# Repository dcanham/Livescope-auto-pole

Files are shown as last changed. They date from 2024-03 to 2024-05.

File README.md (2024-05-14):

# Livescope-auto-pole

# Livescope Pole V1

This project is for controlling a 1 1/8" inch pole that your livescope is mounted on, however it can be updated to fit other poles. Lots of code here for testing, so each folder will be explained below. Bluetooth_and_AP_Mode is the main code that is working and partially tested, it powers on, looks for the most recently connected device, if it does not find it, it will go into "AP" mode where your phone can connect to its wifi. Then go to a browser and go to 192.168.4.1 and a webpage should show. Click "scan" and it will look for bluetooth devices in the area. Select the device you wish to connect and it will shut off the AP and start working. Now each time the device boots up it will look for that device. 

## Parts list:
- ESP32 with 18650: https://a.co/d/enj4STK
- 3v to 5v step up: https://www.pololu.com/product/2562 (required as the ESP only outputs 5v if on USB power)
- Servo: https://a.co/d/6YfNTrJ
- 1" ram mount: https://a.co/d/4ML1X51
- Wireless BT Remote: https://a.co/d/i9t7pQf
- Box: Printed in PETG, files can be found 3d Printed Parts folder. 
- Misc wires and solder
- A 1 and 1/8 livescope pole with hole at top, I used the summit fishing pole. 

## To do:
- Clean Up Code
- Test other bluetooth remotes
- Add comments
- Ajust gears to have deeper teeth for better grip

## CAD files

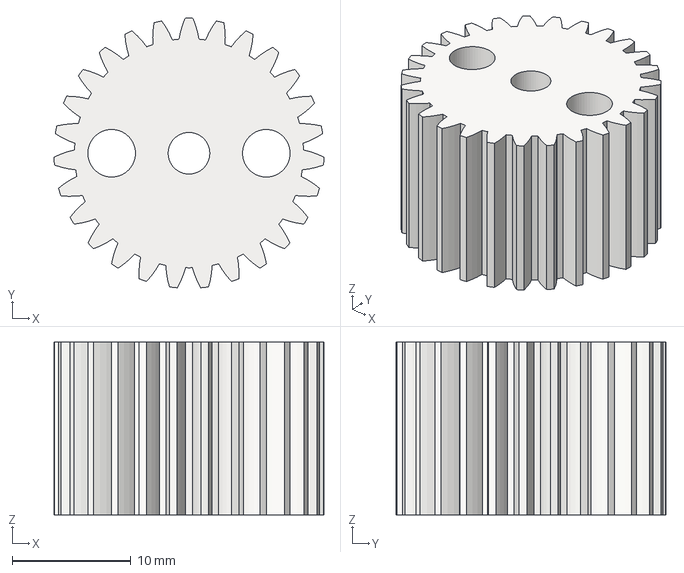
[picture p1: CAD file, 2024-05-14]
3d Printed parts/Little_gear.step
22.7 x 22.7 x 14.5 mm

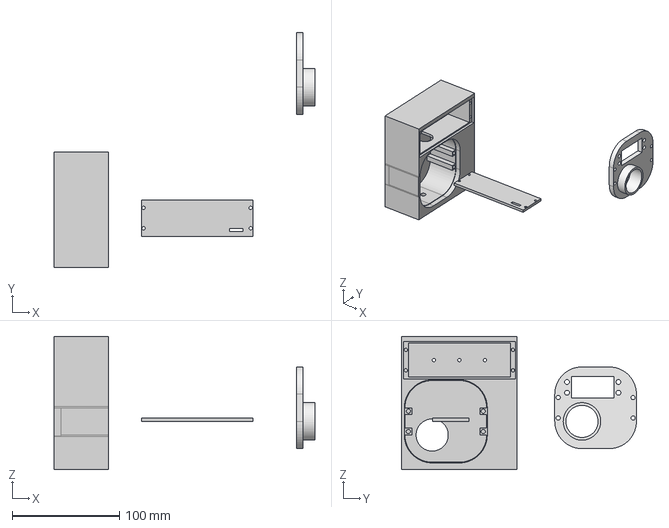
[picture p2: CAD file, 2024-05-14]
3d Printed parts/Livescope_pole_box.step
243.4 x 219.1 x 124.4 mm

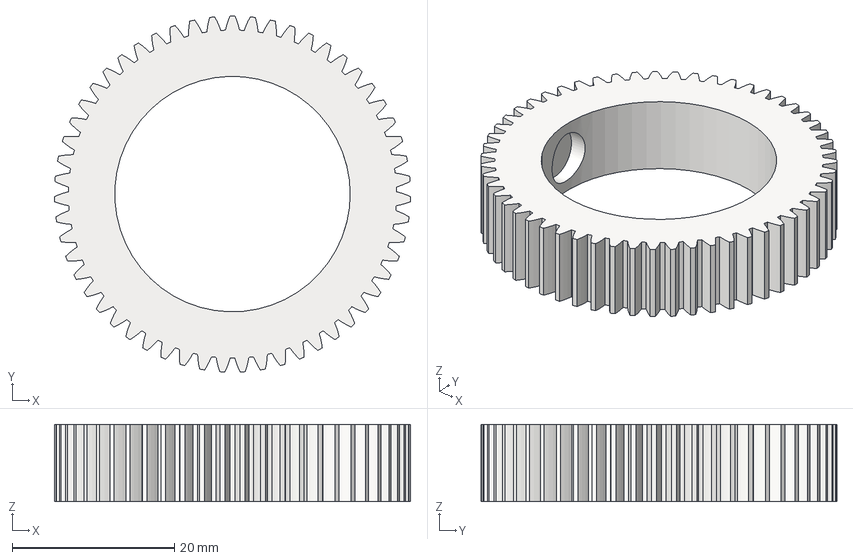
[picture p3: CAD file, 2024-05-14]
3d Printed parts/Big_gear.step
43.9 x 43.8 x 9.53 mm

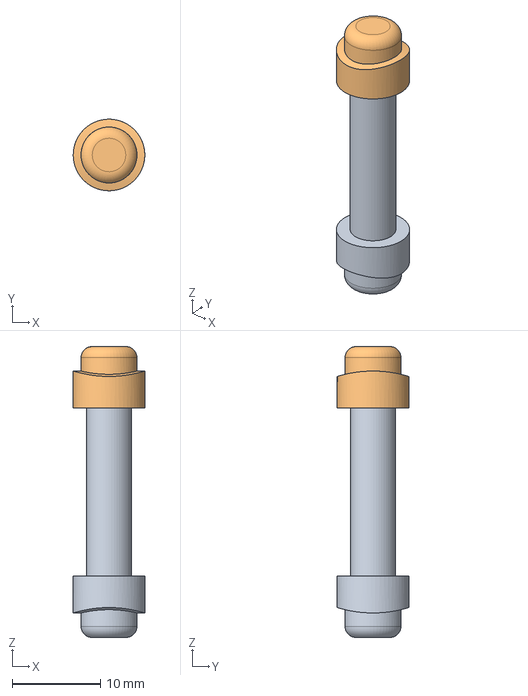
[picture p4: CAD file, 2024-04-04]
3d Printed parts/TPU_Inner_Spring_Rod.step
8.12 x 8.13 x 33.0 mm

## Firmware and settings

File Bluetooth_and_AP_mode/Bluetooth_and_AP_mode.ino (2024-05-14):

#include <WiFi.h>
#include <WebServer.h>
#include <BLEDevice.h>
#include <BLEUtils.h>
#include <BLEScan.h>
#include <BLEAdvertisedDevice.h>
#include <ESP32Servo.h>
#include <EEPROM.h>
#include <Arduino.h>

// Set up variables and things
const char* ssid = "ESP32-AP";
const char* password = "password";
bool isConnected = false;
bool alreadyPrinted = false;
bool wifiOff = false;
bool firstBoot = true;
bool addressEmpty = false;
const int servoPin = 22; // GPIO pin connected to the servo
const int pulseMin = 1250; // Minimum pulse width in microseconds
const int pulseMax = 1750; // Maximum pulse width in microseconds
const int pulseMid = 1500; // Middle pulse width to represent the mid-point
BLEClient* pClient;
WebServer server(80);
BLEScan* pBLEScan;
std::vector<BLEAdvertisedDevice> discoveredDevices;
BLEUUID HID_SERVICE_UUID;
BLEUUID HID_REPORT_CHAR_UUID;
#define CLIENT_CHARACTERISTIC_CONFIG_UUID "00002902-0000-1000-8000-00805f9b34fb"
#define SERVO_PIN 16
#define LEFT_LIMIT 0
#define RIGHT_LIMIT 180
#define EEPROM_ADDR_START 0
#define MAX_STRING_LENGTH 20  // Maximum length of the string to be stored in EEPROM
#define EEPROM_SIZE 200


Servo myservo;
Servo servo;
uint8_t lastButtonState = 0;
int servoPosition = 90;
bool processHIDReport = true;





class MyAdvertisedDeviceCallbacks : public BLEAdvertisedDeviceCallbacks {
public:
  void onResult(BLEAdvertisedDevice advertisedDevice) {
    discoveredDevices.push_back(advertisedDevice);
  }
};

String getLastConnectedDeviceAddress() {
  String data = "";
  char byteRead;
  for (int i = 0; i < MAX_STRING_LENGTH; i++) {
    byteRead = char(EEPROM.read(EEPROM_ADDR_START + i));
    //Serial.print("Read byte: ");
    //Serial.println(byteRead);
    if (byteRead == '\0') {
      break;  // Stop reading if null terminator is encountered
    }
    data += byteRead;
  }

  // Print the read data to serial
  Serial.println("Data read from EEPROM:");
  Serial.println(data);
  return data;
}


void writeToEEPROM(String data) {
  int length = data.length();
  if (length > MAX_STRING_LENGTH - 1) {  // Ensure data fits within EEPROM size
    Serial.println("Data exceeds EEPROM capacity. Truncating...");
    length = MAX_STRING_LENGTH - 1;
    data.substring(0, length);  // Truncate data
  }

  Serial.println("Printing below to EEPROM: ");
  Serial.println(data);
  for (int i = 0; i < length; i++) {
    char byteToWrite = data[i];
    EEPROM.write(EEPROM_ADDR_START + i, byteToWrite);
    //Serial.print("Wrote byte: ");
    //Serial.println(byteToWrite);
  }
  EEPROM.write(EEPROM_ADDR_START + length, '\0');  // Null-terminate the string
  EEPROM.commit();                                 // Commit the changes to EEPROM
}


void handleRoot() {
  String page = "<html><body>";
  page += "<h1>Welcome to ESP32 Web Server</h1>";
  page += "<button onclick=\"window.location.href='/scan'\">Scan</button>";
  page += "</body></html>";
  server.send(200, "text/html", page);
}

void handleScan() {
  discoveredDevices.clear();
  BLEScanResults foundDevices = pBLEScan->start(5);
  server.sendHeader("Location", "/results", true);
  server.send(302, "text/plain", "");
}

void handleResults() {
  String page = "<html><body>";
  page += "<h1>Scan Results</h1>";
  page += "<ul>";
  for (size_t i = 0; i < discoveredDevices.size(); ++i) {
    BLEAdvertisedDevice device = discoveredDevices[i];
    BLEAddress address = device.getAddress();
    String name = device.getName().c_str();
    page += "<li>Address: " + String(address.toString().c_str()) + ", Name: " + String(name.c_str()) + " <button onclick=\"window.location.href='/connect?address=" + String(address.toString().c_str()) + "'\">Connect</button></li>";
  }
  page += "</ul>";

  // Add rescan button
  page += "<button onclick=\"window.location.href='/scan'\">Rescan</button>";

  page += "</body></html>";
  server.send(200, "text/html", page);
}

void registerForNotifications() {
  Serial.println("Started registerForNotifications part");
  BLERemoteService* pService = pClient->getService(HID_SERVICE_UUID);
  if (pService) {
    Serial.println("HID Service found.");
    Serial.print("HID Service UUID: ");
    Serial.println(pService->getUUID().toString().c_str());

    BLERemoteCharacteristic* pCharacteristic = pService->getCharacteristic(HID_REPORT_CHAR_UUID);
    if (pCharacteristic) {
      Serial.println("HID Report Characteristic found.");
      Serial.print("HID Report Characteristic UUID: ");
      Serial.println(pCharacteristic->getUUID().toString().c_str());

      // Use the hardcoded CLIENT_CHARACTERISTIC_CONFIG_UUID here
      const char* CCCD_UUID = "00002902-0000-1000-8000-00805f9b34fb";
      BLEUUID cccdUUID(CCCD_UUID);
      BLERemoteDescriptor* pDescriptor = pCharacteristic->getDescriptor(cccdUUID);
      if (pDescriptor) {
        Serial.println("Client Characteristic Configuration Descriptor found.");
        Serial.print("Client Characteristic Configuration Descriptor UUID: ");
        Serial.println(pDescriptor->getUUID().toString().c_str());

        Serial.println("Registering for notifications on HID report characteristic.");
        pDescriptor->writeValue((uint8_t*)"\x01\x00", 2);  // Enable notifications (0x0001)
        pCharacteristic->registerForNotify(notifyCallback);
        Serial.println("Registered for notifications.");
      } else {
        Serial.println("Failed to find Client Characteristic Configuration Descriptor.");
      }
    } else {
      Serial.println("Failed to find HID Report Characteristic.");
    }
  } else {
    Serial.println("Failed to find HID Service.");
  }
}

void handleConnect() {
  Serial.println("Handling connect request...");
  String addressParam = server.arg("address");  // Get the BLE device address from the URL parameter
  addressParam.trim();                          // Remove leading and trailing whitespace characters

  Serial.println("Connecting to device at address: " + addressParam);

  if (addressParam.length() == 0) {
    Serial.println("No address provided.");
    server.send(400, "text/plain", "No address provided.");
    return;
  }

  BLEAddress address = BLEAddress(addressParam.c_str());  // Convert the address string to BLEAddress object

  // Check if already connected
  if (isConnected) {
    Serial.println("Already connected to a device.");
    server.send(200, "text/plain", "Already connected to a device.");
    return;
  }

  Serial.println("Attempting to connect to the device...");

  // Initialize BLE client
  pClient = BLEDevice::createClient();  // Removed local declaration to use the global one
  if (!pClient) {
    Serial.println("Failed to create BLE client.");
    server.send(500, "text/plain", "Failed to create BLE client.");
    return;
  }

  // Attempt to connect to the device
  if (pClient->connect(address)) {
    Serial.println("Connected to the device.");
    isConnected = true;  // Set connection flag to true
    // Save the connected device address to EEPROM
    writeToEEPROM(addressParam);
    Serial.println("Written to EEProm");


    Serial.println("Connect request handled. Lets anaylze ");

    // Get the HID service UUID and HID report characteristic UUID
    std::map<std::string, BLERemoteService*>* services = pClient->getServices();
    if (services) {
      for (auto& service : *services) {
        std::map<std::string, BLERemoteCharacteristic*>* characteristics = service.second->getCharacteristics();
        if (characteristics) {
          for (auto& characteristic : *characteristics) {
            if (characteristic.second->canNotify()) {
              if (characteristic.second->getUUID().equals(BLEUUID((uint16_t)0x2A4D))) {  // HID report characteristic UUID is 0x2A4D
                Serial.println("Found HID report characteristic.");
                HID_SERVICE_UUID = BLEUUID(service.first);
                HID_REPORT_CHAR_UUID = BLEUUID(characteristic.first);
                registerForNotifications();
                return;
              }
            }
          }
        }
      }
    }
  } else {
    Serial.println("Failed to connect to the device.");
    server.send(500, "text/plain", "Failed to connect to the device.");
  }

  Serial.println("Failed to find HID service or report characteristic.");
}

void handleConnectEEProm(String addressParam) {
  Serial.println("Handling connect request...");
  //String addressParam = server.arg("address"); // Get the BLE device address from the URL parameter
  addressParam.trim();  // Remove leading and trailing whitespace characters

  Serial.println("Connecting to device at address: " + addressParam);

  if (addressParam.length() == 0) {
    Serial.println("No address provided.");
    server.send(400, "text/plain", "No address provided.");
    return;
  }

  BLEAddress address = BLEAddress(addressParam.c_str());  // Convert the address string to BLEAddress object

  // Check if already connected
  // if (isConnected) {
  //     Serial.println("Already connected to a device.");
  //     server.send(200, "text/plain", "Already connected to a device.");
  //     return;
  // }

  Serial.println("Attempting to connect to the device...");

  // Initialize BLE client
  pClient = BLEDevice::createClient();  // Removed local declaration to use the global one
  if (!pClient) {
    Serial.println("Failed to create BLE client.");
    //server.send(500, "text/plain", "Failed to create BLE client.");
    return;
  }

  // Attempt to connect to the device
  if (pClient->connect(address)) {
    Serial.println("Connected to the device.");
    isConnected = true;  // Set connection flag to true
    // Save the connected device address to EEPROM
    writeToEEPROM(addressParam);
    Serial.println("Written to EEProm");


    Serial.println("Connect request handled. Lets anaylze ");

    // Get the HID service UUID and HID report characteristic UUID
    std::map<std::string, BLERemoteService*>* services = pClient->getServices();
    if (services) {
      for (auto& service : *services) {
        std::map<std::string, BLERemoteCharacteristic*>* characteristics = service.second->getCharacteristics();
        if (characteristics) {
          for (auto& characteristic : *characteristics) {
            if (characteristic.second->canNotify()) {
              if (characteristic.second->getUUID().equals(BLEUUID((uint16_t)0x2A4D))) {  // HID report characteristic UUID is 0x2A4D
                Serial.println("Found HID report characteristic.");
                HID_SERVICE_UUID = BLEUUID(service.first);
                HID_REPORT_CHAR_UUID = BLEUUID(characteristic.first);
                registerForNotifications();
                return;
              }
            }
          }
        }
      }
    }
  } else {
    Serial.println("Failed to connect to the device.");
    //server.send(500, "text/plain", "Failed to connect to the device.");
  }

  Serial.println("Failed to find HID service or report characteristic.");
}

void notifyCallback(BLERemoteCharacteristic* pCharacteristic, uint8_t* pData, size_t length, bool isNotify) {
  if (isNotify && processHIDReport) {
    Serial.print("Notification received from characteristic: ");
    Serial.println(pCharacteristic->getUUID().toString().c_str());

    Serial.print("Received HID Report: ");
    for (int i = 0; i < length; i++) {
      Serial.print(pData[i], HEX);
      Serial.print(" ");
    }
    Serial.println();
    // Check if the HID report is a terminating report (0 0)
    if (length >= 2 && pData[0] == 0x00 && pData[1] == 0x00) {
      Serial.println("Terminating HID Report received. Ready to process next HID Report.");
      processHIDReport = true;  // Set flag to process next HID report
    } else {
      // Check HID report and control servo accordingly
      if (length >= 2) {
        if (pData[0] == 0xEA && pData[1] == 0x00) {  // Volume down button
          Serial.println("Volume down button pressed. Moving servo left.");
          myservo.writeMicroseconds(pulseMin);
          delay(200);
          myservo.writeMicroseconds(pulseMid);
        } else if (pData[0] == 0xE9 && pData[1] == 0x00) {  // Volume up button
          Serial.println("Volume up button pressed. Moving servo right.");
          myservo.writeMicroseconds(pulseMax);
          delay(200);
          myservo.writeMicroseconds(pulseMid);
        }
      }
      processHIDReport = false;  // Set flag to skip processing subsequent HID reports until a terminating report is received
    }
    // Update last button state regardless of the button press
    lastButtonState = pData[0];
  } else if (isNotify && !processHIDReport) {
    // Check if the HID report is a terminating report (0 0)
    if (length >= 2 && pData[0] == 0x00 && pData[1] == 0x00) {
      Serial.println("Terminating HID Report received. Ready to process next HID Report.");
      processHIDReport = true;  // Set flag to process next HID report
    }
  }
}


void setup() {
  Serial.begin(115200);
  WiFi.softAP(ssid, password);
  Serial.println("Access Point started. Connect to: " + String(ssid));
  Serial.print("Server IP address: ");
  Serial.println(WiFi.softAPIP());
  BLEDevice::init("");
  pBLEScan = BLEDevice::getScan();
  pBLEScan->setAdvertisedDeviceCallbacks(new MyAdvertisedDeviceCallbacks());
  server.on("/", HTTP_GET, handleRoot);
  server.on("/scan", HTTP_GET, handleScan);
  server.on("/results", HTTP_GET, handleResults);
  server.on("/connect", HTTP_GET, handleConnect);
  server.begin();
  // Initialize servo

  myservo.setPeriodHertz(50);    // Standard 50Hz servo
  myservo.attach(servoPin, pulseMin, pulseMax);  // attaches the servo on pin to the servo object
                                                 // and defines min and max pulse widths
  //servo.attach(SERVO_PIN);
  EEPROM.begin(EEPROM_SIZE);

  //String testaddress = "00:11:22:33:44:55"; // Example Bluetooth address
  //writeToEEPROM(testaddress);


  Serial.println("Servo initialized.");
  String eepromData = getLastConnectedDeviceAddress();
  Serial.print("Last connected device address: ");
  Serial.println(eepromData);
}

void loop() {

  if (firstBoot) {
    // Attempt to connect to the stored Bluetooth address on first boot

    firstBoot = false;
    String eepromData = getLastConnectedDeviceAddress();
    Serial.print("Last connected device address: ");
    Serial.println(eepromData);

    if (eepromData.length() == 0) {
      Serial.println("No address provided.");
      addressEmpty = true;

    } else {
      Serial.print("Address Provided lets connect");
      handleConnectEEProm(eepromData);
    }

    if (!isConnected && addressEmpty) {
      // Proceed with normal boot process if connection fails
      Serial.print("Address Empty, not connecting and trying normal boot on next void loop run");
    } else if (isConnected){
      //we conencted, lets clean up wifi and output
      alreadyPrinted = true;
      // Turn off Wifi to save power
      WiFi.mode(WIFI_OFF);

      Serial.println("WiFi AP disabled because we connected to a previously known device.");
      wifiOff = true;
    } else {
      Serial.println("We didn't connect to an older device so we'll move on back to void loop");

    }

  } else {
    // Proceed with normal boot process
    if (!isConnected) {
      Serial.println("No device connected. Let's try to find one.");
      server.handleClient();  // This should only be called when a client is connected and sending requests
    }

    if (isConnected && !alreadyPrinted && !wifiOff) {
      alreadyPrinted = true;
      // Disable WiFi AP
      WiFi.softAPdisconnect(true);
      delay(200);

      // Optionally, you can also turn off WiFi completely
      WiFi.mode(WIFI_OFF);

      Serial.println("WiFi AP disabled. ");
      wifiOff = true;
    }
  }

  delay(200);
}

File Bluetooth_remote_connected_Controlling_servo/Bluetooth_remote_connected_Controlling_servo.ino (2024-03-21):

#include <BLEDevice.h>
#include <BLEUtils.h>
#include <BLEClient.h>
#include <BLECharacteristic.h>
#include <ESP32Servo.h>

#define HID_SERVICE_UUID "00001812-0000-1000-8000-00805f9b34fb"
#define HID_REPORT_CHAR_UUID "00002A4D-0000-1000-8000-00805f9b34fb"
#define CLIENT_CHARACTERISTIC_CONFIG_UUID "00002902-0000-1000-8000-00805f9b34fb"
#define SERVO_PIN 16

BLEClient* pClient;
BLERemoteCharacteristic* pReportCharacteristic;
Servo servo;

#define LEFT_LIMIT 0     // Adjust left limit (in degrees)
#define RIGHT_LIMIT 180   // Adjust right limit (in degrees)

uint8_t lastButtonState = 0;   // Variable to store the last button state
int servoPosition = 90;        // Initial servo position (in degrees)
bool processHIDReport = true; // Flag to indicate whether to process HID reports

void notifyCallback(BLERemoteCharacteristic* pCharacteristic, uint8_t* pData, size_t length, bool isNotify) {
    if (isNotify && processHIDReport) {
        Serial.print("Notification received from characteristic: ");
        Serial.println(String(pCharacteristic->getUUID().toString().c_str()));
        Serial.print("Received HID Report: ");
        for (int i = 0; i < length; i++) {
            Serial.print(pData[i], HEX);
            Serial.print(" ");
        }
        Serial.println();

        // Check if the HID report is a terminating report (0 0)
        if (length >= 2 && pData[0] == 0x00 && pData[1] == 0x00) {
            Serial.println("Terminating HID Report received. Ready to process next HID Report.");
            processHIDReport = true; // Set flag to process next HID report
        } else {
            // Check HID report and control servo accordingly
            if (length >= 2) {
                if (pData[0] == 0xEA && pData[1] == 0x00) { // Volume down button
                    Serial.println("Volume down button pressed. Moving servo left.");
                    if (servoPosition > LEFT_LIMIT) {
                        servoPosition -= 10; // Decrease servo position by 10 degrees
                        servo.write(servoPosition);
                    } else {
                        // Flip around to the other side
                        servoPosition = RIGHT_LIMIT;
                        servo.write(servoPosition);
                    }
                } else if (pData[0] == 0xE9 && pData[1] == 0x00) { // Volume up button
                    Serial.println("Volume up button pressed. Moving servo right.");
                    if (servoPosition < RIGHT_LIMIT) {
                        servoPosition += 10; // Increase servo position by 10 degrees
                        servo.write(servoPosition);
                    } else {
                        // Flip around to the other side
                        servoPosition = LEFT_LIMIT;
                        servo.write(servoPosition);
                    }
                }
            }
            processHIDReport = false; // Set flag to skip processing subsequent HID reports until a terminating report is received
        }
        // Update last button state regardless of the button press
        lastButtonState = pData[0];
    } else if (isNotify && !processHIDReport) {
        // Check if the HID report is a terminating report (0 0)
        if (length >= 2 && pData[0] == 0x00 && pData[1] == 0x00) {
            Serial.println("Terminating HID Report received. Ready to process next HID Report.");
            processHIDReport = true; // Set flag to process next HID report
        }
    }
}







void setup() {
    Serial.begin(115200);
    Serial.println("Starting...");

    // Initialize BLE
    BLEDevice::init("");

    // Connect to the BLE HID device
    pClient = BLEDevice::createClient();
    BLEAddress deviceAddress("c7:a3:e8:b2:b1:a9");
    if (!pClient->connect(deviceAddress)) {
        Serial.println("Failed to connect to the device.");
        return;
    }
    Serial.println("Connected to the device.");

    // Get the HID service
    BLERemoteService* pRemoteService = pClient->getService(BLEUUID(HID_SERVICE_UUID));
    if (pRemoteService == nullptr) {
        Serial.println("Failed to find HID service.");
        return;
    }

    // Get the Report characteristic
    pReportCharacteristic = pRemoteService->getCharacteristic(BLEUUID(HID_REPORT_CHAR_UUID));
    if (pReportCharacteristic == nullptr) {
        Serial.println("Failed to find HID report characteristic.");
        return;
    }
    Serial.println("HID report characteristic found.");

    // Enable notifications for the report characteristic
    if (!pReportCharacteristic->canNotify()) {
        Serial.println("Notifications are not supported for HID report characteristic.");
        return;
    }
    Serial.println("Enabling notifications for HID report characteristic...");
    pReportCharacteristic->getDescriptor(BLEUUID(CLIENT_CHARACTERISTIC_CONFIG_UUID))->writeValue("0100", true);

    // Register for notifications
    pReportCharacteristic->registerForNotify(notifyCallback);
    Serial.println("Registered for notifications.");

    // Initialize servo
    servo.attach(SERVO_PIN);
    Serial.println("Servo initialized.");
}

void loop() {
    // You can add additional functionality here if needed
}

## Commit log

2024-03-19 Code For bluetooth serial controlling servo
2024-03-21 update servo limits
2024-03-29 Working Bluetooth and AP Mode
    Working with wifi AP and bluetooth to control servo
2024-04-04 3d printed files and most test folders
    included v1 of the build of 3d files and a couple more test codes
    [Big_gear_v2.step, Plate_v2.step, Small_Gear_v2.step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]
2024-05-14 Update servo and servo swipe
2024-05-14 Update 3D printed object files
    [Big_gear.step, Big_gear_v2.step, Little_gear.step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]
